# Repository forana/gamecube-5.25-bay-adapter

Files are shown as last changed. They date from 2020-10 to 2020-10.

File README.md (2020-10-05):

# 5.25" Bay Adapter for Gamecube Controller Adapter... Adapter

This is a 3D model of a bracket adapter to mount a [Mayflash Wii U/PC USB Gamecube Controller Adapter](https://www.amazon.com/Mayflash-GameCube-Controller-Adapter-Switch/dp/B00RSXRLUE)'s internals inside a standard 5.25" drive bay slot. Because, y'know, why not.

This was inspired by [https://www.thingiverse.com/thing:1948219](https://www.thingiverse.com/thing:1948219), which uses the official adapter instead of this offbrand one. I did print that and get it installed, but the official adapter requires some _nasty_ driver manipulation to get working properly - this one just works.

See [gamecube-5.25-bay.stl](gamecube-5.25-bay.stl) in this repo for a 3D preview.

*If you print this, please let me know - it'd make me real happy.*

## Pics

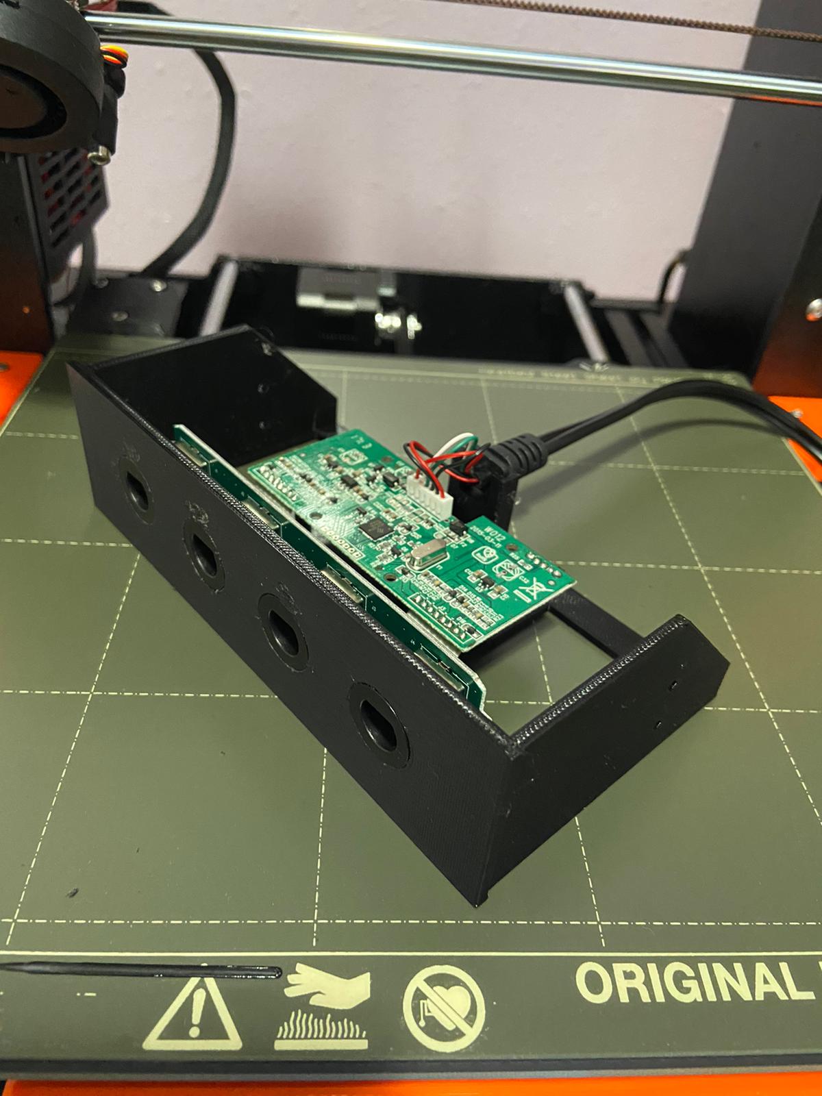
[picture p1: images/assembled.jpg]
Assembled

(Note the screw holes being unused - my first version had the posts flipped around and were useless)

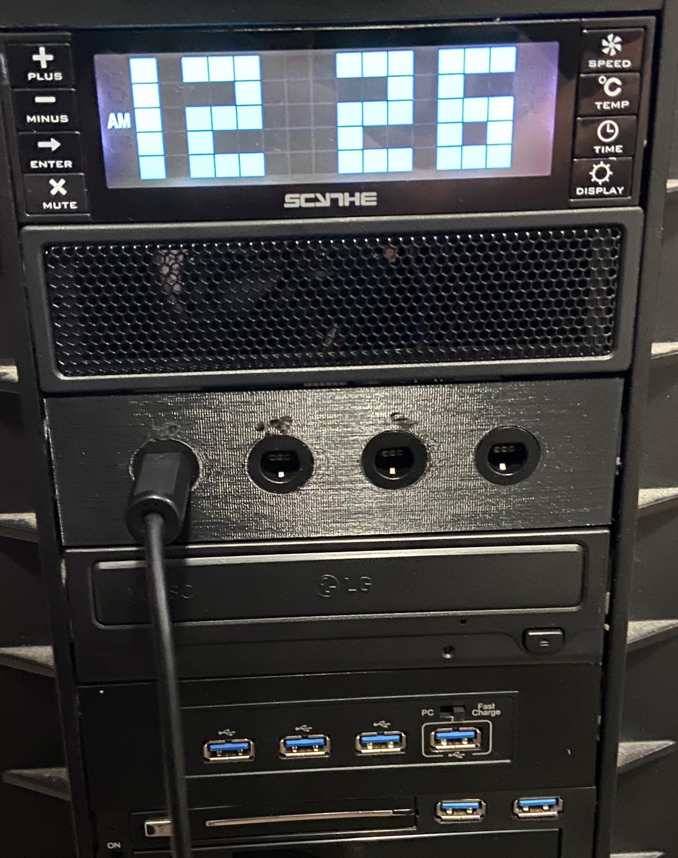
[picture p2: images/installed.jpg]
Installed


## Assembly

1. Slice and print (note - if your printer isn't terribly accurate, you probably won't have great results - my measurements were somewhat precise). I did 0.15mm layer height with generic PLA and no supports - I had to do a _little_ bit of cleanup with a dremel for the port overhangs, but it turned out mostly ok.
2. Make sure the switch on the adapter is in the "PC" position, then disassemble the adapter. Keep at least 4 of the screws, but you can toss the plastic shell if you want. Be careful not to wiggle the ribbon cables between the two boards too much - the wires don't seem that strong and I was worried about breaking them all constantly.
3. Once the print is complete and cleaned up, start attaching the board by sliding the ports in first. You _may_ want to dremel out some space in the ports if your printer didn't handle the overhang super well (but be careful - you can see the marks I accidentally made above a few of the ports in my pics). Once the ports pop in, they should slide into the little clips on the riser in there. Be gentle, but firm.
4. Use the 4 screws from the original case to attach the main board to the riser posts.
5. Slide the cord into the little stand for it. It should be a pretty snug fit.

## Installation

Really just like any other 5.25" bay device - slide the cables in first, then connect via the mounting holes. My case is a tool-less design and that worked just fine, but standard M3 screws _should_ work as well. If you have internal USB ports, you can connect via those - I ended up removing a PCI slot cover from the back of the case and threading the cables out to the rear ports through that (my desktop _is_ a rat's nest of cabling, thanks for asking).

## Anyway

Now I've got gamecube ports on my desktop. Hooray?

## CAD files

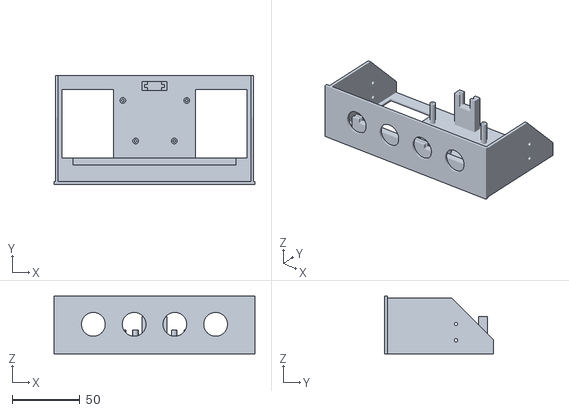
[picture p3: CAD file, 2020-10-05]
gamecube-5.25-bay.stl
148.0 x 80.0 x 42.5

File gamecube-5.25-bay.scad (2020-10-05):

// module for adapting the board + sockets of the mayflash Wii U/PC gamecube adapter
// to a standard 5.25" drive bay slot, because why not
// https://www.amazon.com/Mayflash-GameCube-Controller-Adapter-Switch/dp/B00RSXRLUE
// inspired by https://www.thingiverse.com/thing:1948219 - the official adapter
// requires some _weird_ monkey business with drivers, and I'm not about that life

// renders with controller ports facing "front"

use <socket.scad>

$fn = 64;

socketPCBWidth = ceil(115.11);
socketPCBHeight = ceil(18.72);
socketPCBThickness = 1.3;
socketPCBInset = 16.75;
socketPlateWidth = 18;
socketSpacing = 12;
boardYOffset = 11;
boardZOffset = 5.7;
mainPCBWidth = 80.5;
mainPCBHeight = 36.2;

// back left, from top, relative to main board 
hole1X = 17;
hole1Y = 3.5;
// front left
hole2X = 26.3;
hole2Y = mainPCBHeight - 2.85;
// back right
hole3X = mainPCBWidth - 16.5;
hole3Y = hole1Y;
// front right
hole4X = mainPCBWidth - 25.7;
hole4Y = hole2Y;

screwPostDiameter = 4.2;
screwHoleDiameter = 1.95; // screws are actually around 2.05mm thick
screwLength = 8;

cordNeckWidth = 10;
cordNeckHeight = 6;
cordNeckThickness = 2.8;
cordCollarWidth = 14.5;
cordCollarHeight = 10;
cordCollarThickness = 2.3;

// bay dimensions sourced from https://assets.euchner.de/sirius/26066.jpg
// did you know a 5.25" drive front plate is actually around 5.825" wide?
// me neither. I hate everything.

bayFrontWidth = 148;
bayFrontHeight = 42.5;
bayFrontThickness = 2;
bayBaseThickness = 1.5;
bayBoxHeight = 41;
bayBoxWidth = 146;
bayHoleDiameter = 2.5; // M3 screws

// front bottom
bayHole1X = 52.5;
bayHole1Y = 10;
// front top
bayHole2X = bayHole1X;
bayHole2Y = 22;
// back bottom
bayHole3X = 132.5;
bayHole3Y = bayHole1Y;

bayDepth = 80;

moduleZOffset = (bayFrontHeight - socketPCBHeight)/2;

module driveBaySled() {
    // front
    translate([-bayFrontWidth/2, 0, 0])
        cube([bayFrontWidth, bayFrontThickness, bayFrontHeight]);
    // floor + sides
    translate([-bayBoxWidth/2, 0, 0]) difference() {
        cube([bayBoxWidth, bayDepth, bayBoxHeight]);
        // interior cutout
        translate([bayFrontThickness, bayFrontThickness, bayBaseThickness])
            cube([bayBoxWidth-2*bayFrontThickness, bayDepth, bayBoxHeight]);
        // mounting holes
        translate([-0.1, bayHole1X, bayHole1Y])
            rotate([0, 90, 0])
                cylinder(d = bayHoleDiameter, h = bayBoxWidth + 0.2);
        translate([-0.1, bayHole2X, bayHole2Y])
            rotate([0, 90, 0])
                cylinder(d = bayHoleDiameter, h = bayBoxWidth + 0.2);
        translate([-0.1, bayHole3X, bayHole3Y])
            rotate([0, 90, 0])
                cylinder(d = bayHoleDiameter, h = bayBoxWidth + 0.2);
        // angled cutout because why not cause problems for ourselves
        translate([-bayFrontThickness/2, bayDepth + bayFrontHeight/4, 0])
            rotate([45, 0, 0])
                cube(bayFrontWidth);
    };
}

module driveBaySledWithHoles() {
    difference() {
        driveBaySled();
        translate([-1.5*socketSpacing - 2*socketPlateWidth, -0.01, moduleZOffset + socketPCBHeight]) union() {
            for (i=[0:3]) {
                translate([i*socketPlateWidth + i*socketSpacing, 0, 0])
                    mayflashSocket();
            }
        }
    }
}

module socketPCBSupports() {
    supportWallThickness = 2;
    translate([(socketPCBWidth + 4)/-2, socketPCBInset - supportWallThickness - 0.5*socketPCBThickness, 0]) difference() {
        cube([socketPCBWidth + 4, 2*supportWallThickness + socketPCBThickness, socketPCBHeight/6 + moduleZOffset]);
        translate([-0.5, supportWallThickness, moduleZOffset]) {
            cube([socketPCBWidth + 5, socketPCBThickness, socketPCBHeight]);
        }
        translate([2 + socketPCBWidth/2 + socketSpacing/2, -0.5, moduleZOffset])
            cube([2*socketPlateWidth + socketSpacing, 2*supportWallThickness + socketPCBThickness + 1, socketPCBHeight]);
        translate([2 + socketPCBWidth/2 - socketSpacing*1.5 - socketPlateWidth*2, -0.5, moduleZOffset])
            cube([2*socketPlateWidth + socketSpacing, 2*supportWallThickness + socketPCBThickness + 1, socketPCBHeight]);
    }
}

module screwPost(x, y) {
    translate([x, mainPCBHeight - y, 0]) difference() {
        cylinder(d = screwPostDiameter, h = moduleZOffset + boardZOffset);
        translate([0, 0, moduleZOffset + boardZOffset - screwLength])
            cylinder(d = screwHoleDiameter, h = screwLength * 2);
    }
}

module cableSupport() {
    supportWall = 2;
    supportWidth = cordCollarWidth + 2*supportWall;
    supportDepth = cordCollarThickness + 2*supportWall;
    translate([-supportWidth/2, socketPCBInset + socketPCBThickness + boardYOffset + mainPCBHeight + 4, 0]) difference () {
        cube([supportWidth, supportDepth, moduleZOffset + boardZOffset + cordCollarHeight]);
        // collar inset
        translate([supportWall, supportWall, moduleZOffset + boardZOffset])
            cube([cordCollarWidth, cordCollarThickness, cordCollarWidth]);
        // cables cutouts
        translate([supportWall + (cordCollarWidth - cordNeckWidth)/2, -0.5, moduleZOffset + boardZOffset])
            cube([cordNeckWidth, supportDepth + 1, cordCollarWidth]);
    }
}

// cut out some base material for time/material saving
module materialSaverCutout() {
    cutoutXStart = mainPCBWidth / 2 - 10;
    cutoutYStart = socketPCBInset + socketPCBThickness/2 + 2;
    translate([cutoutXStart, cutoutYStart, -0.5])
        cube([bayBoxWidth/2 - 5 - cutoutXStart, bayDepth - 10 - cutoutYStart, bayBaseThickness + 1]);
}

// whole thing assembled
difference() {
    union() {
        driveBaySledWithHoles();
        socketPCBSupports();
        translate([-mainPCBWidth/2, socketPCBInset + socketPCBThickness + boardYOffset, 0]) union() { 
            screwPost(hole1X, hole1Y);
            screwPost(hole2X, hole2Y);
            screwPost(hole3X, hole3Y);
            screwPost(hole4X, hole4Y);
        };
        cableSupport();
    };
    materialSaverCutout();
    mirror([1, 0, 0]) materialSaverCutout();
}

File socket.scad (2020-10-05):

// module for just the socket part of the mayflash adapter
// https://www.amazon.com/Mayflash-GameCube-Controller-Adapter-Switch/dp/B00RSXRLUE
// really just the black plastic part at the tip

// renders vertically with the controller port facing "forward".
// the top _should_ line up with the precise edge of the ports PCB

$fn = 64;

// "socket" = the round part
socketWidth = ceil(16.93) + 0.5;
socketRadius = socketWidth/2;
socketDepth = ceil(3.8);
// "plate" = the bigger part that we're going to use to hold the things in place
plateWidth = ceil(17.88);
plateRadius = plateWidth/2;
plateDepth = 1.6;
// "extension" = how far back to pretend the socket goes for spacing/arrangement
extensionDepth = socketDepth;

module mayflashSocket() {
    rotate([-90, 0, 0]) union() {
        // socket + extension
        translate([plateRadius, plateRadius, 0])
            cylinder(d = socketWidth, h = socketDepth + plateDepth + extensionDepth);
        // plate (really a cylinder + a rect)
        translate([plateRadius, plateRadius, extensionDepth])
            cylinder(d = plateWidth, h = plateDepth);
        translate([0, 0, extensionDepth])
            cube([plateWidth, plateRadius, plateDepth]); 
    };
}

mayflashSocket();
